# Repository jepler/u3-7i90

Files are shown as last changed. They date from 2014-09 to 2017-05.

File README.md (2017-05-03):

# u3-7i90

This repository will hold the design files for the level adaptor from ODROID U3 to Mesa 7i90, as well as instructions on building a Linux kernel for the ODROID with the necessary customizations.

# Development status

The author (@jepler) is not actively using or developing this project.
Issues and pull requests are not likely to be acted on.
I would be interested in passing this project to a new maintainer.

# The board


(I do not receive any compensation from oshpark when you order my design)

## Theory

The TXB0104 level translator is used for voltage conversion between the ODROID (1.8v I/O standard) and 7i90 (3.3v I/O standard).  I had success running at up to 40MHz, but by the TXB datasheet a safe rate is more like 30MHz.  (in any case, even at 30MHz, setup / cleanup time dominates SPI transaction time so choose a reliable rate rather than a fast one)

## Design Files

The board was designed in Eagle 6.6.  The board files may not be readable in earlier versions.

## Assembling and installing the board

Most of the assembly should be straightforward.  Two things to note:

 * You MUST use appropriate spacers between the two boards to keep the connectors well-aligned.  The 2mm connectors are fragile; I ruined them and had to rework the board, which was not a lot of fun.
 * The connectors go on the top (owl) side, the surface-mount parts go on the bottom (blank) side.
 * I recommend that you work in this order:
  * Solder all items but the connectors
  * Insert the 2mm male headers into the odroid's female headers
  * put the level adapter board on top with the spacers in between
  * solder the 2mm male headers onto the level adapter board
  * solder the 26-pin header

This assembly method is somewhat forgiving of overlong spacers, as long as some of the solder tail of the male headers still sticks into the board.  You want to avoid using too-short spacers, as this will flex the boards.  In theory the assembly distance should be 6mm.

# The software 
## OS
I use the Ubuntu 14.04 image from hardkernel, but probably a debian userspace would work just as well.

## Kernel

You'll have to build your own kernel; there's no packaged kernel at this time.

Use the kernel source tree at https://github.com/jepler/odroid-linux, branch odroid-3.8.13-rt.  The configuration you want is `arch/arm/configs/odroidu_defconfig`.  I build the kernels on an amd64 debian machine using an arm compiler from gcc-4.7-arm-linux-gnueabihf.

TODO: add links to installation instructions; split cross-scripts out 

cross configuring script:

```
ARCH=arm make ${1-menuconfig}
```

cross building script:

```
#!/bin/bash
set -xe

extraversion=

export ARCH=arm
export DEB_HOST_ARCH=armhf

export CONCURRENCY_LEVEL=`getconf _NPROCESSORS_ONLN`
fakeroot make-kpkg --arch arm --cross-compile arm-linux-gnueabihf- --initrd ${extraversion:+--append-to-version=$extraversion} kernel_image kernel_headers

make ARCH=arm CROSS_COMPILE=arm-linux-gnueabihf- ${extraversion:+EXTRAVERSION=$extraversion} zImage
cp arch/arm/boot/zImage ../zImage
```

### Known problems

The kernel crashes when it receives a byte on the serial terminal.  However,
early boot messages can still be seen via the serial port if necessary, and
of course you can intercept uboot and boot the original kernel if you really
need to interact via the serial console.

## Misc files

`misc-files` contains important files I've customized.

## LinuxCNC

Use LinuxCNC master branch configured for uspace.  Everything should be just
about normal.

Consider booting with isolcpus=3 to improve latency a bit.

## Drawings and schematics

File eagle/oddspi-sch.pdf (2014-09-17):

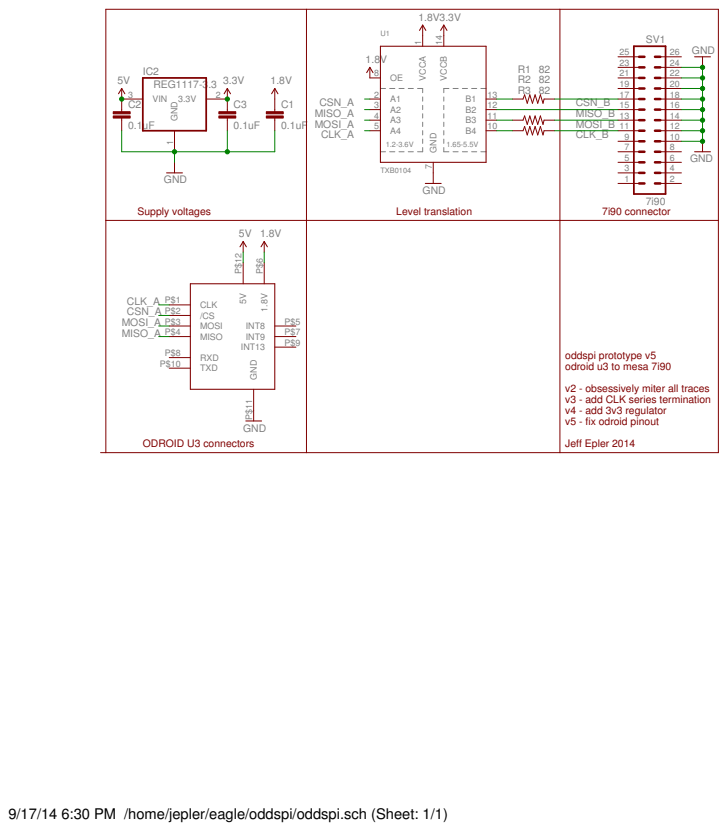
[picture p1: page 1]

oddspi prototype v5
odroid u3 to mesa 7i90
v2 - obsessively miter all traces
v3 - add CLK series termination
v4 - add 3v3 regulator v5 - fix odroid pinout

9/17/14 6:30 PM /home/jepler/eagle/oddspi/oddspi.sch (Sheet: 1/1)

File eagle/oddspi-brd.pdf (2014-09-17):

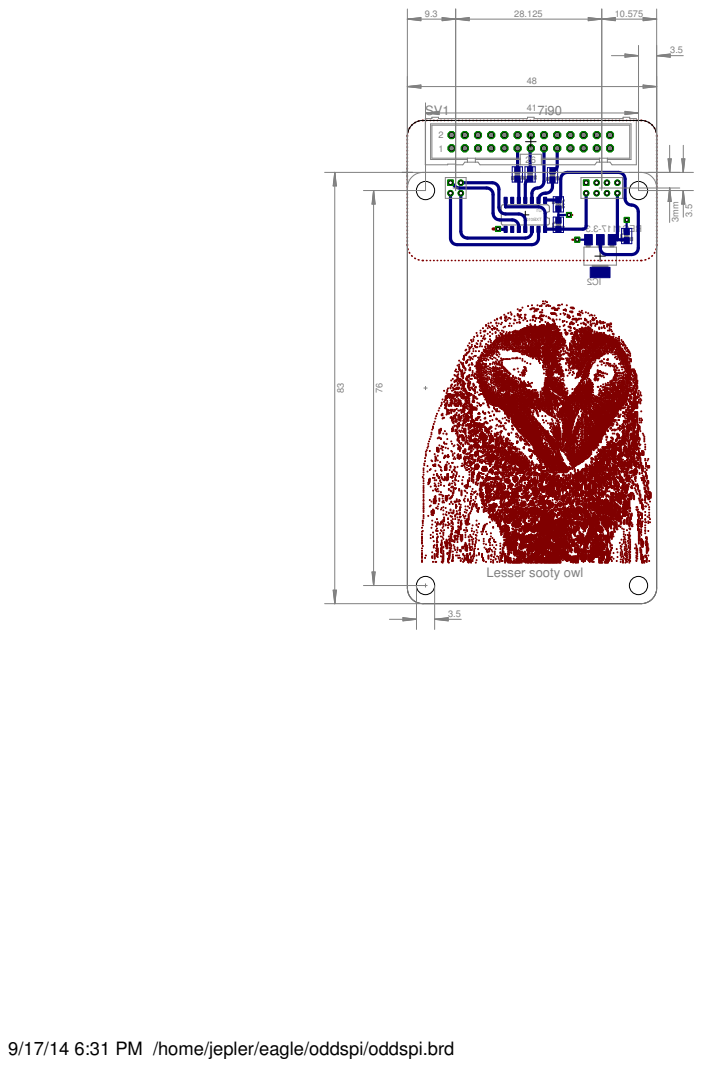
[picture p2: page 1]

9/17/14 6:31 PM /home/jepler/eagle/oddspi/oddspi.brd

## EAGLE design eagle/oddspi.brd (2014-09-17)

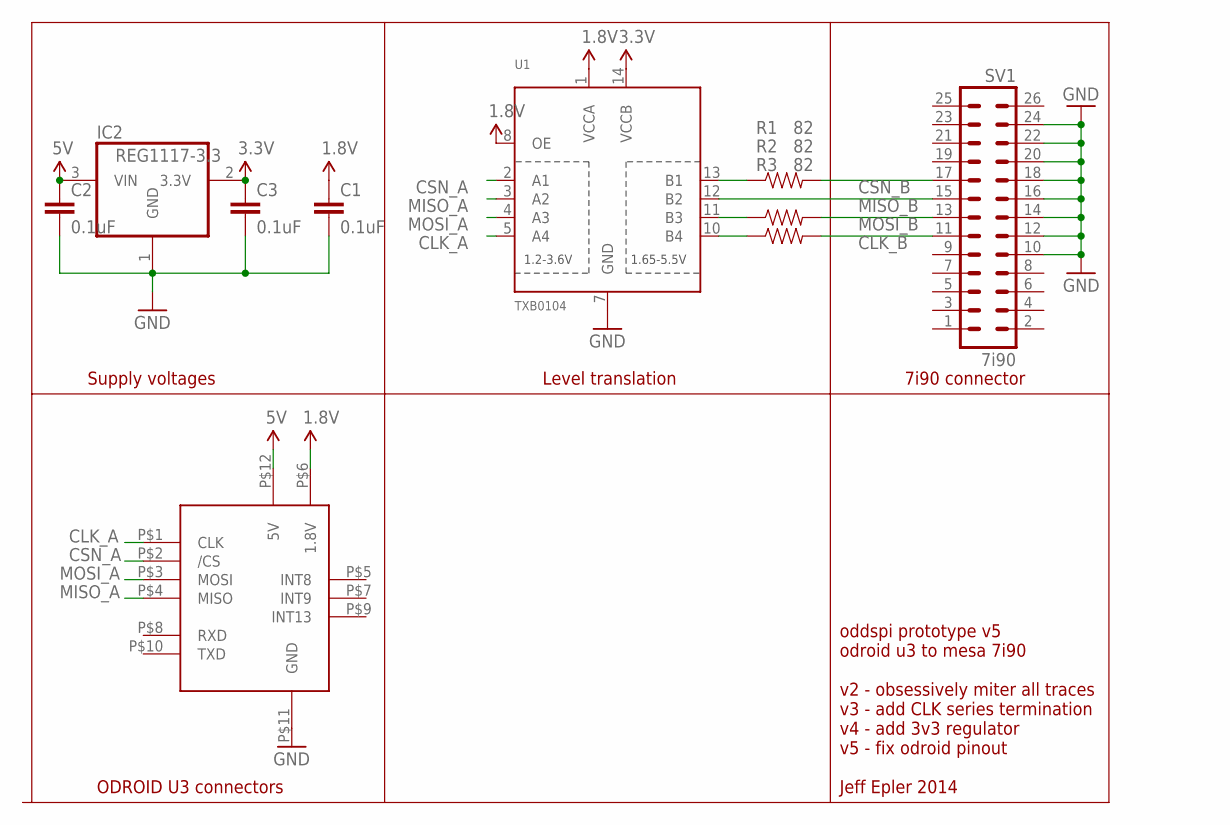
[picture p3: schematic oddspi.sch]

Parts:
C1, C2, C3: 0.1uF; 0603-CAP
IC2: REG1117-3.3; SOT223
R1, R2, R3: 82; 0603-RES
SV1: 7i90; ML26
U1: TXB0104; SO14
U$4: ODROID-U3; U3V05

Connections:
1.8V: C1.1, U1.1 (VCCA), U1.8 (OE), U$4.P$6 (1.8V)
3.3V: C3.1, IC2.2 (3.3V), U1.14 (VCCB)
5V: C2.1, IC2.3 (VIN), U$4.P$12 (5V)
CLK_A: U1.5 (A4), U$4.P$1 (CLK)
CLK_B: R1.2, SV1.11
CSN_A: U1.2 (A1), U$4.P$2 (/CS)
CSN_B: R3.2, SV1.17
GND: C1.2, C2.2, C3.2, IC2.1 (GND), SV1.10, SV1.12, SV1.14, SV1.16, SV1.18, SV1.20, SV1.22, SV1.24, U1.7 (GND), U$4.P$11 (GND)
MISO_A: U1.3 (A2), U$4.P$4 (MISO)
MISO_B: SV1.15, U1.12 (B2)
MOSI_A: U1.4 (A3), U$4.P$3 (MOSI)
MOSI_B: R2.2, SV1.13
unnamed: R1.1, U1.10 (B4)
unnamed: R3.1, U1.13 (B1)
unnamed: R2.1, U1.11 (B3)

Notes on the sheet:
ODROID U3 connectors
Supply voltages
Level translation
7i90 connector
oddspi prototype v5 odroid u3 to mesa 7i90 v2 - obsessively miter all traces v3 - add CLK series termination v4 - add 3v3 regulator v5 - fix odroid pinout Jeff Epler 2014

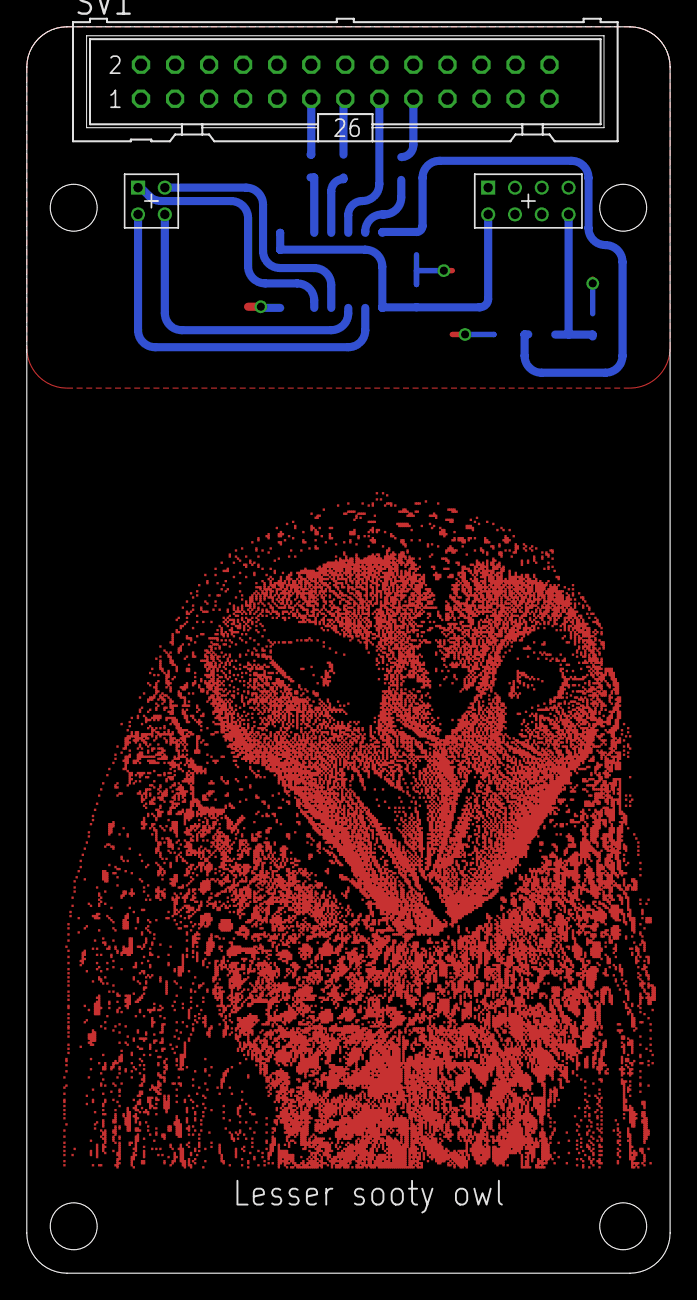
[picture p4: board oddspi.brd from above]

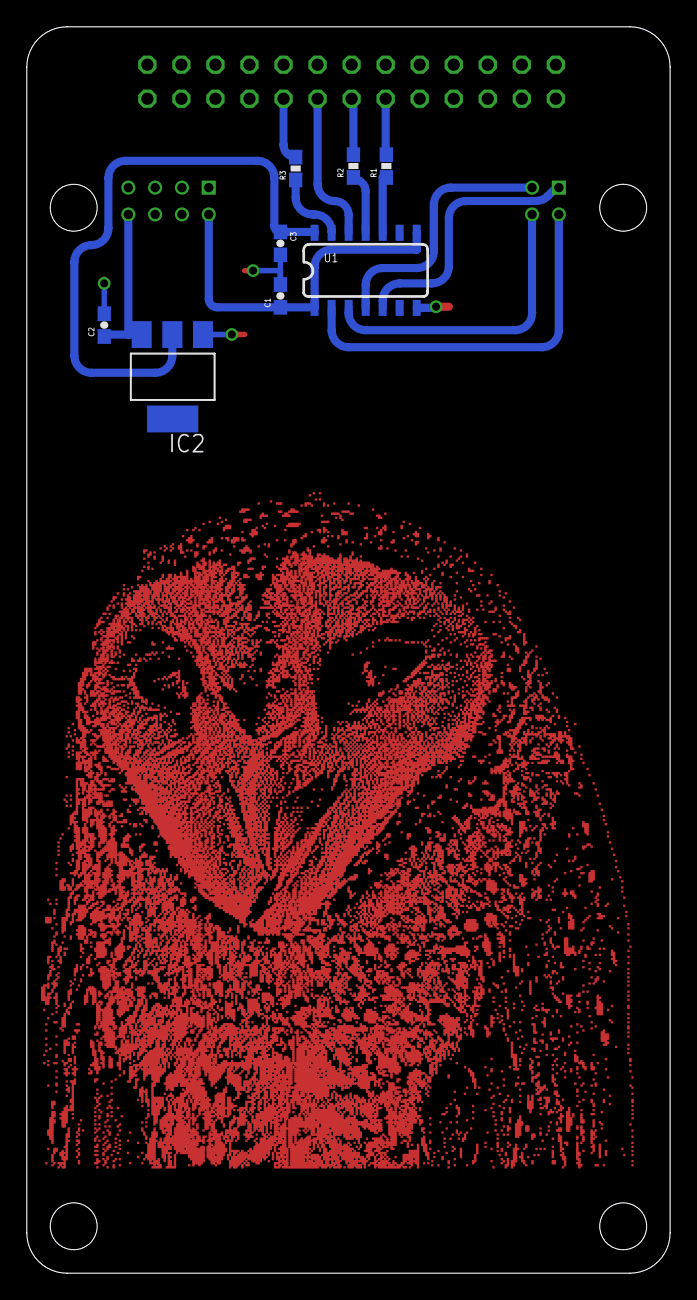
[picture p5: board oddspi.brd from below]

Board: 2 copper layers, 48.0 x 93.0 mm, 10 parts (8 on the bottom side), 15 nets.

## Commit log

2014-09-17 files used in eagle to make the board
    [oddspi.brd, oddspi.sch]
2014-09-17 result of printing the schematic and board in eagle
2014-09-17 A note about the board assembly

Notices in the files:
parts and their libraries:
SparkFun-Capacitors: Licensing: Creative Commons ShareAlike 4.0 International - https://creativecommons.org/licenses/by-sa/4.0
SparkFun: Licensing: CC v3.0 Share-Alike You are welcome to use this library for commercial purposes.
